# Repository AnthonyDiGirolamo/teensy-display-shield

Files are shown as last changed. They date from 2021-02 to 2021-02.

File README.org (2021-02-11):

* teensy-display-shield

  Handheld [[https://excamera.com/sphinx/gameduino3/][Gameduino3]] display shield for the [[https://www.pjrc.com/store/teensy41.html][Teensy 4.1]], [[https://www.pjrc.com/store/teensy36.html][3.6]] or [[https://www.adafruit.com/category/946][Adafruit Feather form
  factor boards]].

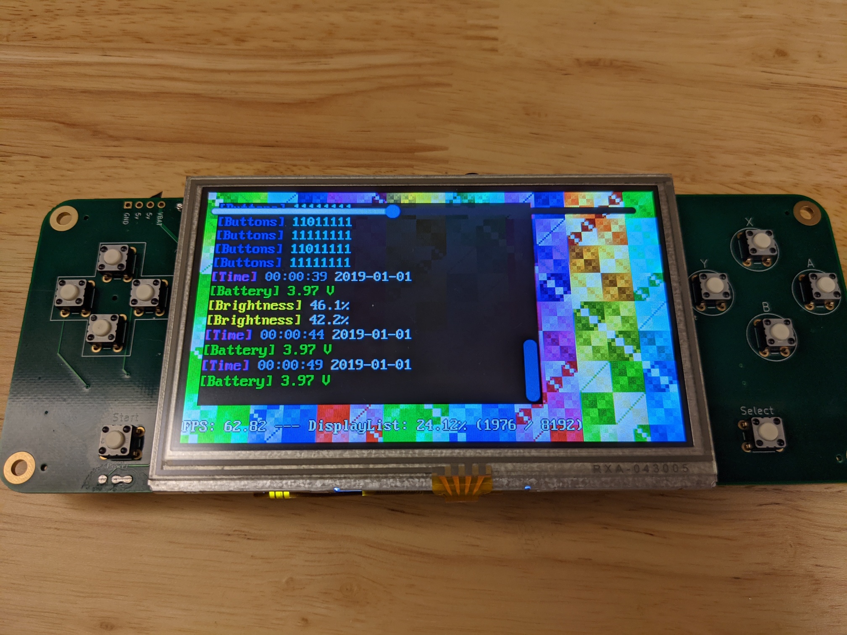
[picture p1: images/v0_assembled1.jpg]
  

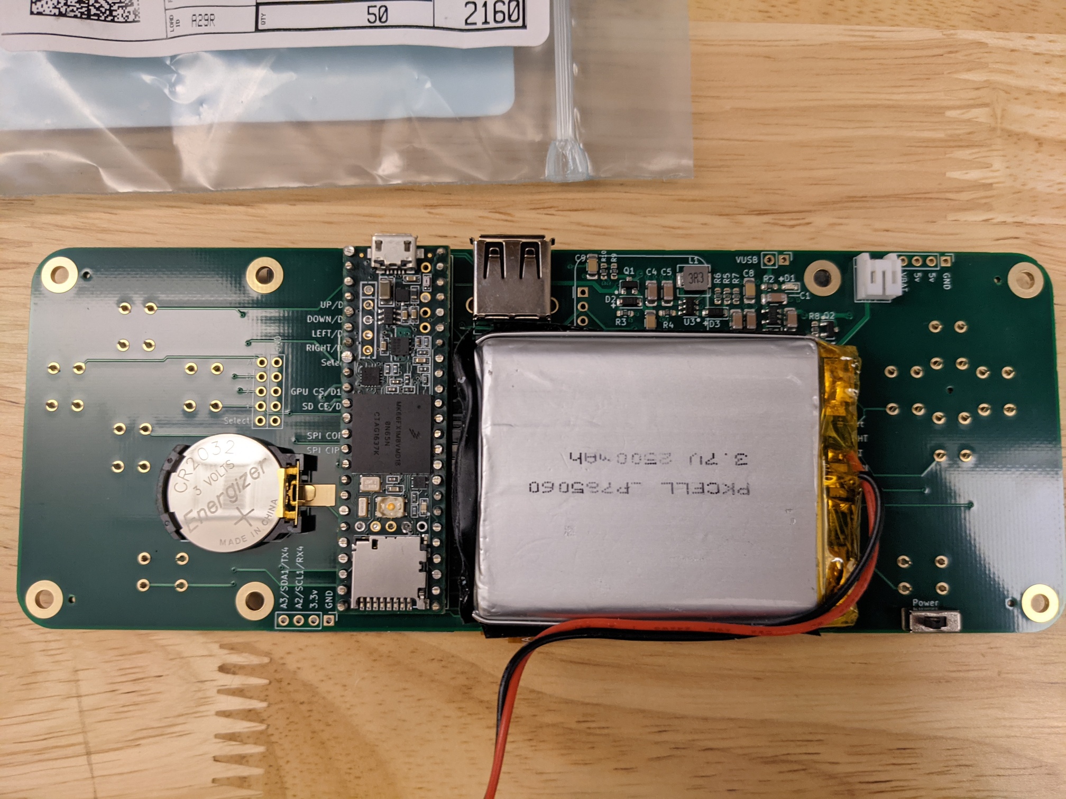
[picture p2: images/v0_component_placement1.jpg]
  

** Version 0

*** Features

    - Teensy and Feather headers.
    - Arduino shield header for use with a Gameduino3 screen.
    - USB-A host jack for Teensy 3.6 and 4.1 boards. For plugging in an external
      keyboard, mouse, or controller.
    - 3v coin cell footprint for Teensy RTC.
    - Through hole buttons for up, down, left, right, a, b, x, y, start, select.
    - On board power:
      - LiPo charging using the [[https://lcsc.com/product-detail/PMIC-Battery-Management_TOPPOWER-Nanjing-Extension-Microelectronics-TP4054_C32574.html][TP4054]] (at 500mA charge-rate).
      - 5 volt boost regulator using the [[https://lcsc.com/product-detail/DC-DC-Converters_Feeling-Tech-FP6291LR-G1_C18701.html][FP6291]]. This powers the Gameduino3 and Teensy.
      - Load sharing between USB and charging.
      - Battery power slide switch.

*** Eratta

    Charging the battery won't work with the power switch in the off
    positon. One cut and jumper wire is needed. See these images:

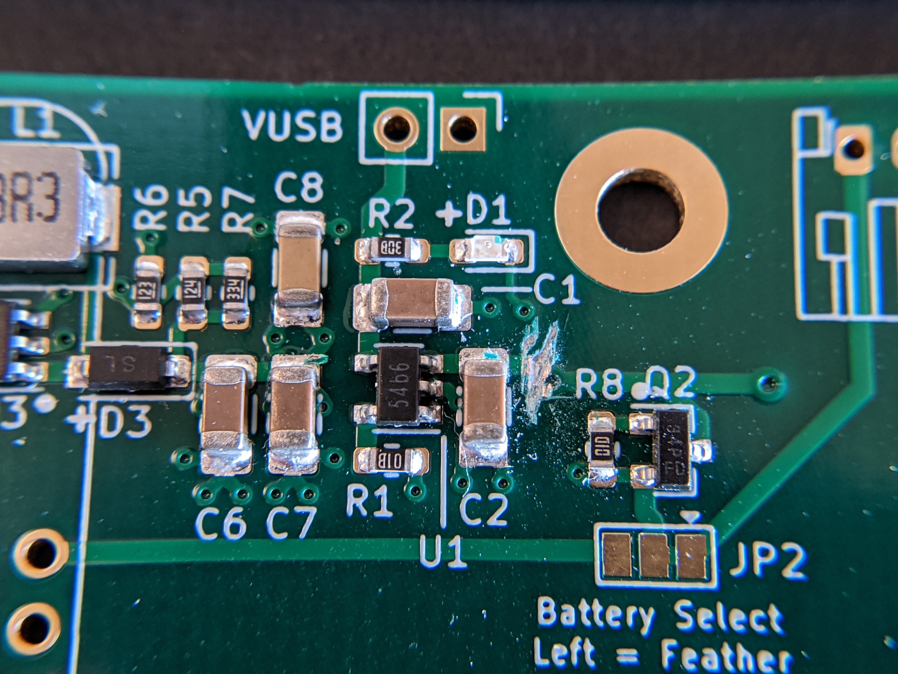
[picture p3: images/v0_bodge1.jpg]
    

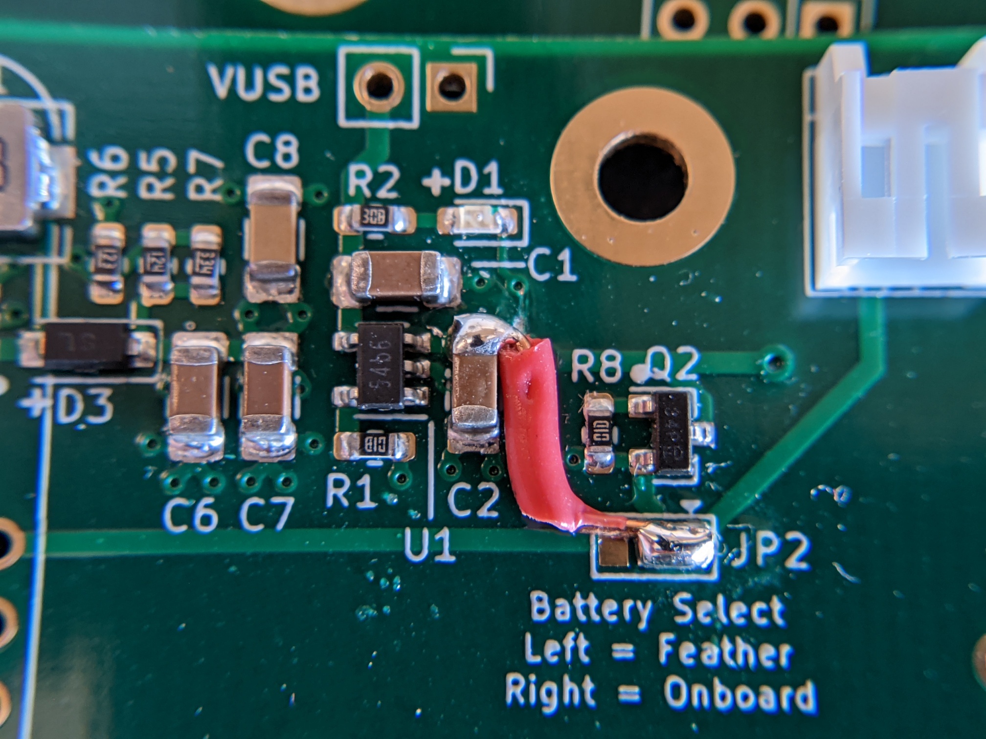
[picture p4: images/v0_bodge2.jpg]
    

** Version 1

*** Required Fixes
    - Correct missing silkscreen pin labels
    - Make all through hole GND connections square pads.

*** Planned Features
    - Push-button on/off operation using [[https://web.archive.org/web/20201001131408/http://www.mosaic-industries.com/embedded-systems/microcontroller-projects/electronic-circuits/push-button-switch-turn-on/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][this schematic]].
    - L and R shoulder buttons.
    - Analog sticks?
    - [[https://www.crowdsupply.com/excamera/gameduino-3x-dazzler][Gameduino 3X Dazzler]] surface mount footprint.
    - Display panel FPC connector and backlight driver.
    - Solder jumpers to control battery charge rate.

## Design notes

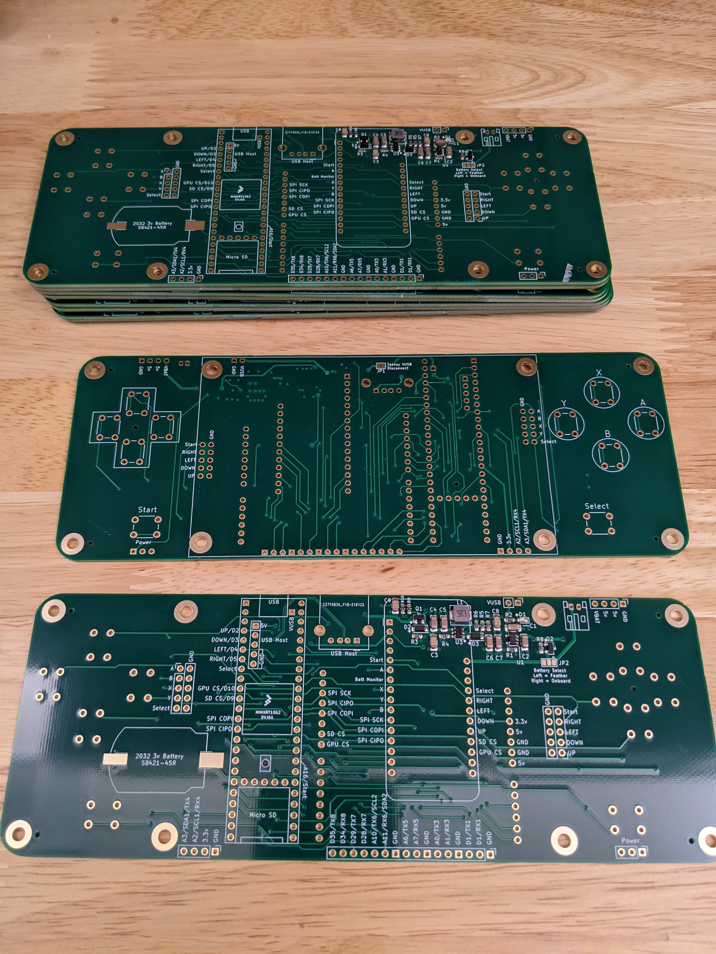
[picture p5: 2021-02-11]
images/v0_boards.jpg

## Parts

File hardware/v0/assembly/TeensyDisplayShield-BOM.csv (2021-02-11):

Comment | Designator | Footprint | LCSC
Adafruit_Feather_Generic | A1 | Module_Latest:Adafruit_Feather
Arduino_UNO_R2 | A2 | Module_Latest:Arduino_UNO_R2
Coin_Cell_2032 | BT1 | Teensy:CoinCell2032HarwinS8421-45R-HandSolder
100nF | C3,C8,C9 | Capacitor_SMD:C_1206_3216Metric_Pad1.33x1.80mm_HandSolder | C24497
10uF | C1,C2,C4,C5,C6,C7 | Capacitor_SMD:C_1206_3216Metric_Pad1.33x1.80mm_HandSolder | C13585
LED-RED | D1 | LED_SMD:LED_0603_1608Metric_Pad1.05x0.95mm_HandSolder | C2286
B5819W | D2,D3 | Diode_SMD:D_SOD-123 | C8598
MountingHole_Pad | H1,H2,H3,H4,H5,H6,H7,H8 | MountingHole:MountingHole_3.2mm_M3_Pad
JSTPH | J1 | Connector_JST:JST_PH_S2B-PH-K_1x02_P2.00mm_Horizontal
USB_A | J2 | Connector_USB:USB_A_Molex_67643_Horizontal
Serial Breakouts | J3 | Connector_PinHeader_2.54mm:PinHeader_1x16_P2.54mm_Vertical
I2C1 Breakout | J4 | Connector_PinHeader_2.54mm:PinHeader_1x04_P2.54mm_Vertical
VBAT/5v Breakout Header | J5 | Connector_PinHeader_2.54mm:PinHeader_1x04_P2.54mm_Vertical
VBUS Breakout Header | J6 | Connector_PinHeader_2.54mm:PinHeader_1x02_P2.54mm_Vertical
Conn_02x05_Top_Bottom | J7,J8 | Connector_PinHeader_2.54mm:PinHeader_2x05_P2.54mm_Vertical
SolderJumper_2_Bridged | JP1 | Jumper:SolderJumper-2_P1.3mm_Bridged2Bar_Pad1.0x1.5mm
Battery Select | JP2 | Jumper:SolderJumper-3_P1.3mm_Bridged12_Pad1.0x1.5mm
3.3uH | L1 | Inductor_SMD:L_Sunlord_MWSA0518_5.4x5.2mm | C408336
DMG3415UQ | Q1,Q2 | Package_TO_SOT_SMD:SOT-23 | C459537
1k | R1 | Resistor_SMD:R_0603_1608Metric_Pad0.98x0.95mm_HandSolder | C21190
10M | R9,R10 | Resistor_SMD:R_0603_1608Metric_Pad0.98x0.95mm_HandSolder | C7250
2k | R2 | Resistor_SMD:R_0603_1608Metric_Pad0.98x0.95mm_HandSolder | C22975
100k | R3,R8 | Resistor_SMD:R_0603_1608Metric_Pad0.98x0.95mm_HandSolder | C25803
10k | R4 | Resistor_SMD:R_0603_1608Metric_Pad0.98x0.95mm_HandSolder | C25804
120k | R5 | Resistor_SMD:R_0603_1608Metric_Pad0.98x0.95mm_HandSolder | C25808
12k | R6 | Resistor_SMD:R_0603_1608Metric_Pad0.98x0.95mm_HandSolder | C22790
330k | R7 | Resistor_SMD:R_0603_1608Metric_Pad0.98x0.95mm_HandSolder | C23137
Battery Switch | SW1 | Connector_PinHeader_2.54mm:PinHeader_1x03_P2.54mm_Vertical
SW_Push | SW2,SW3,SW4,SW5,SW6,SW7,SW8,SW9,SW10,SW11 | Button_Switch_THT:SW_PUSH_6mm
TP4054 | U1 | Package_TO_SOT_SMD:SOT-23-5 | C32574
Teensy4.1 | U2 | Teensy:Teensy41NoEthernet
FP6291LR-G1 | U3 | Package_TO_SOT_SMD:SOT-23-6 | C18701

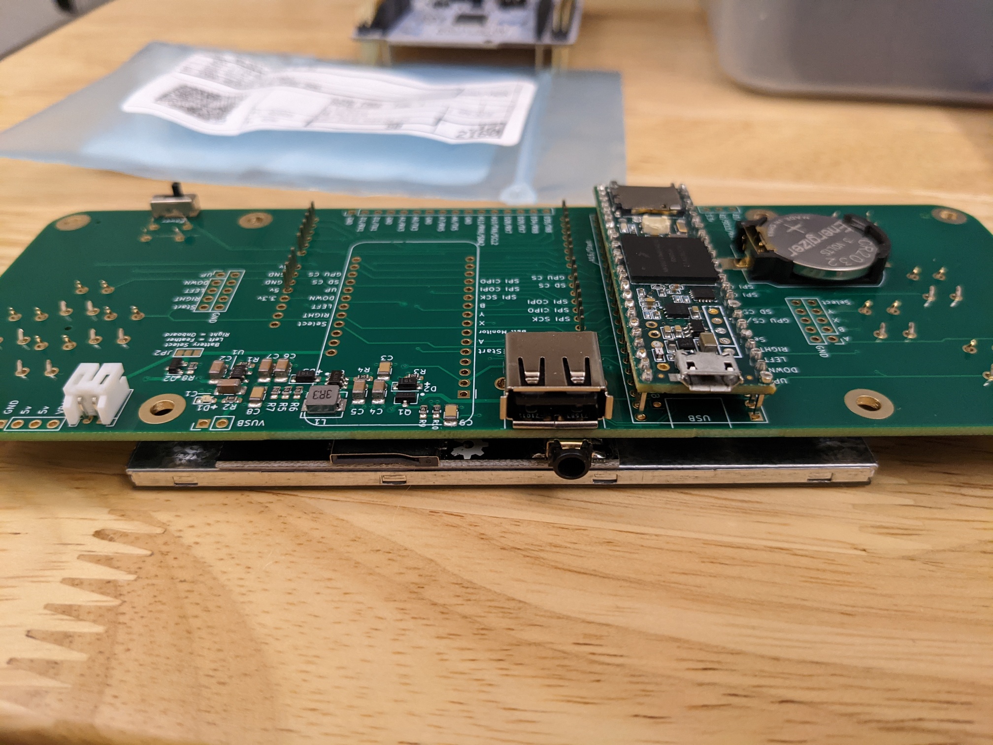
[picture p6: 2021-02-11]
images/v0_component_placement2.jpg

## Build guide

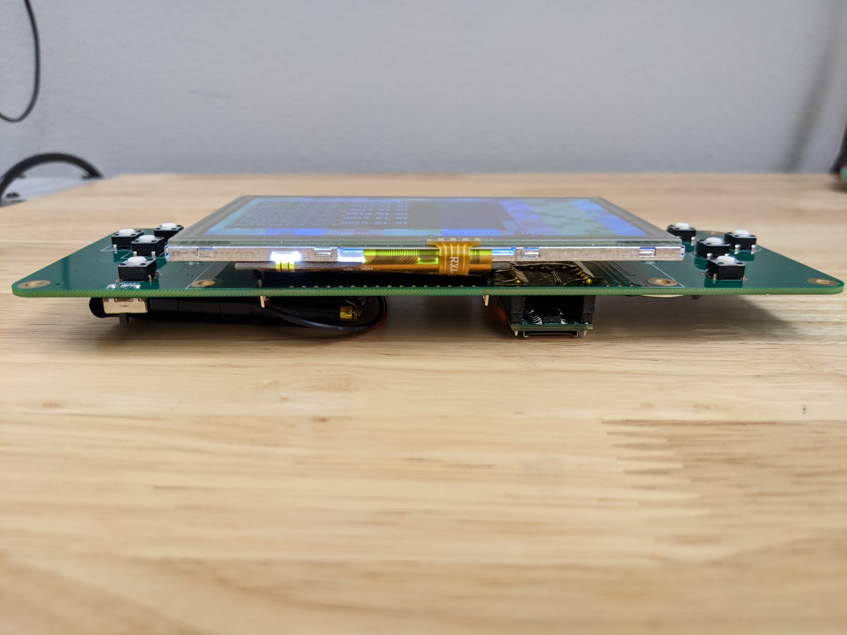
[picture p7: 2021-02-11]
images/v0_assembled2.jpg

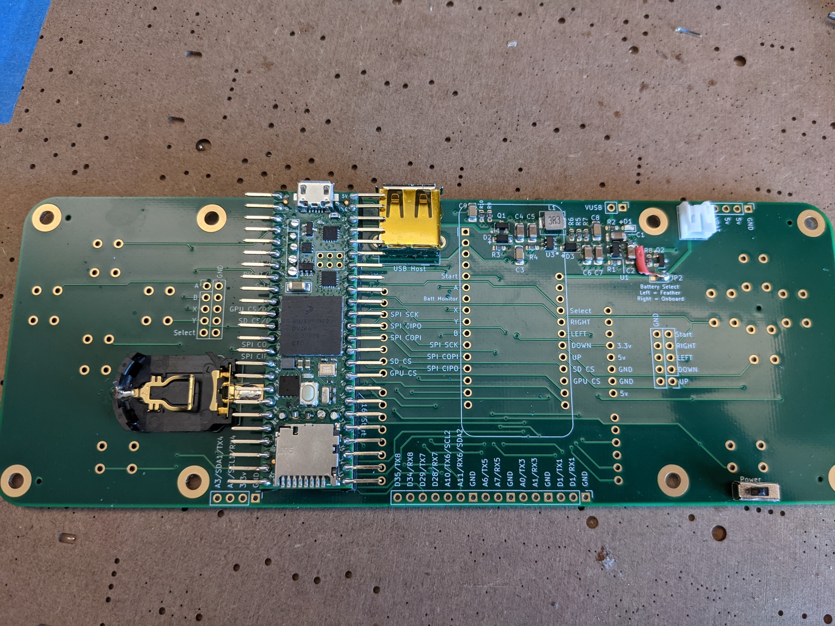
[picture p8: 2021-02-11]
images/v0_assembled3.jpg

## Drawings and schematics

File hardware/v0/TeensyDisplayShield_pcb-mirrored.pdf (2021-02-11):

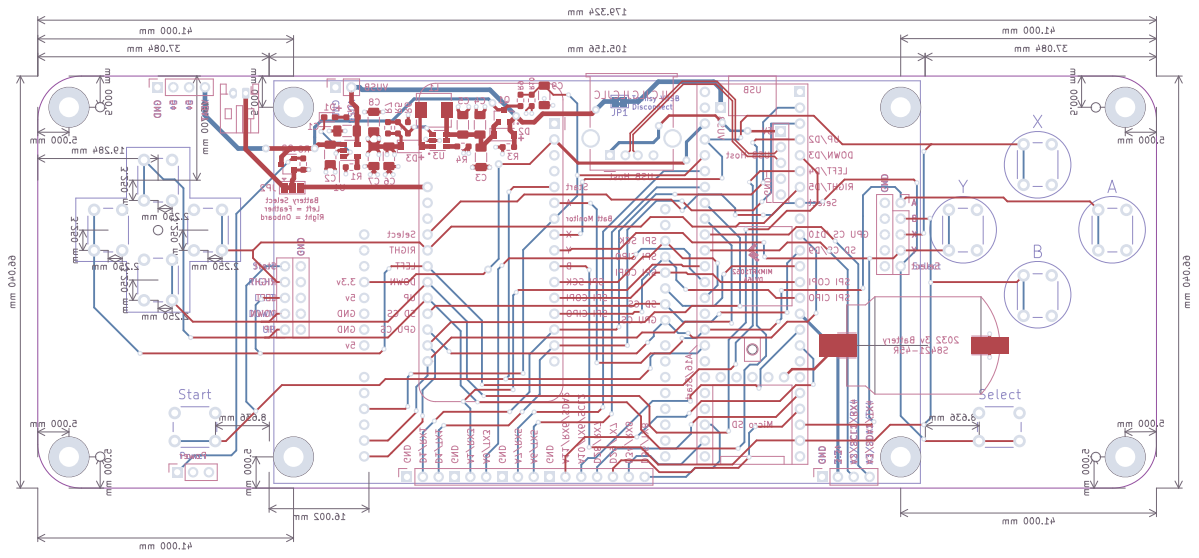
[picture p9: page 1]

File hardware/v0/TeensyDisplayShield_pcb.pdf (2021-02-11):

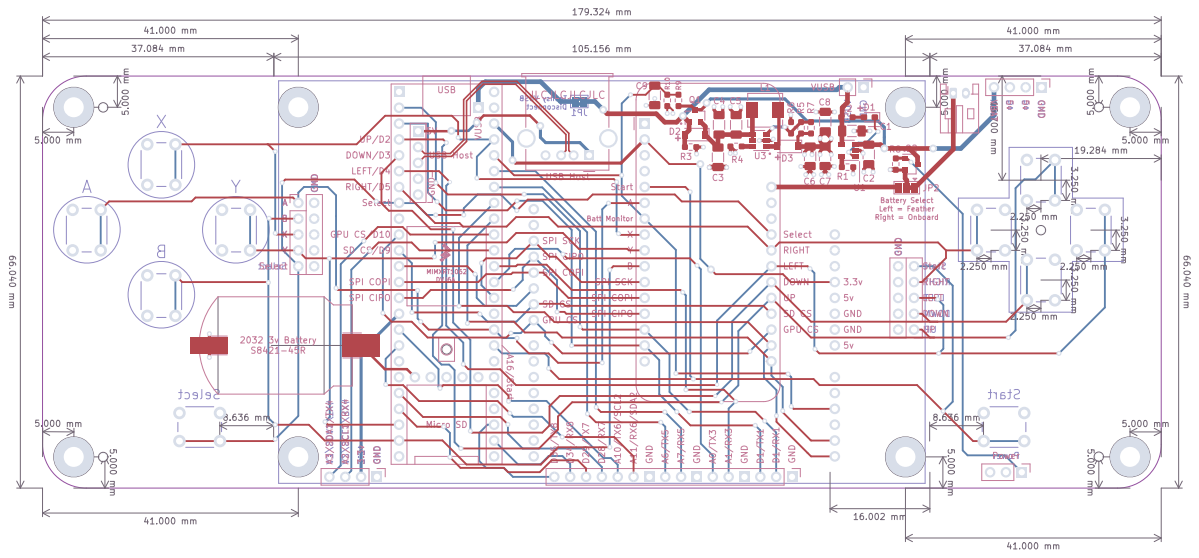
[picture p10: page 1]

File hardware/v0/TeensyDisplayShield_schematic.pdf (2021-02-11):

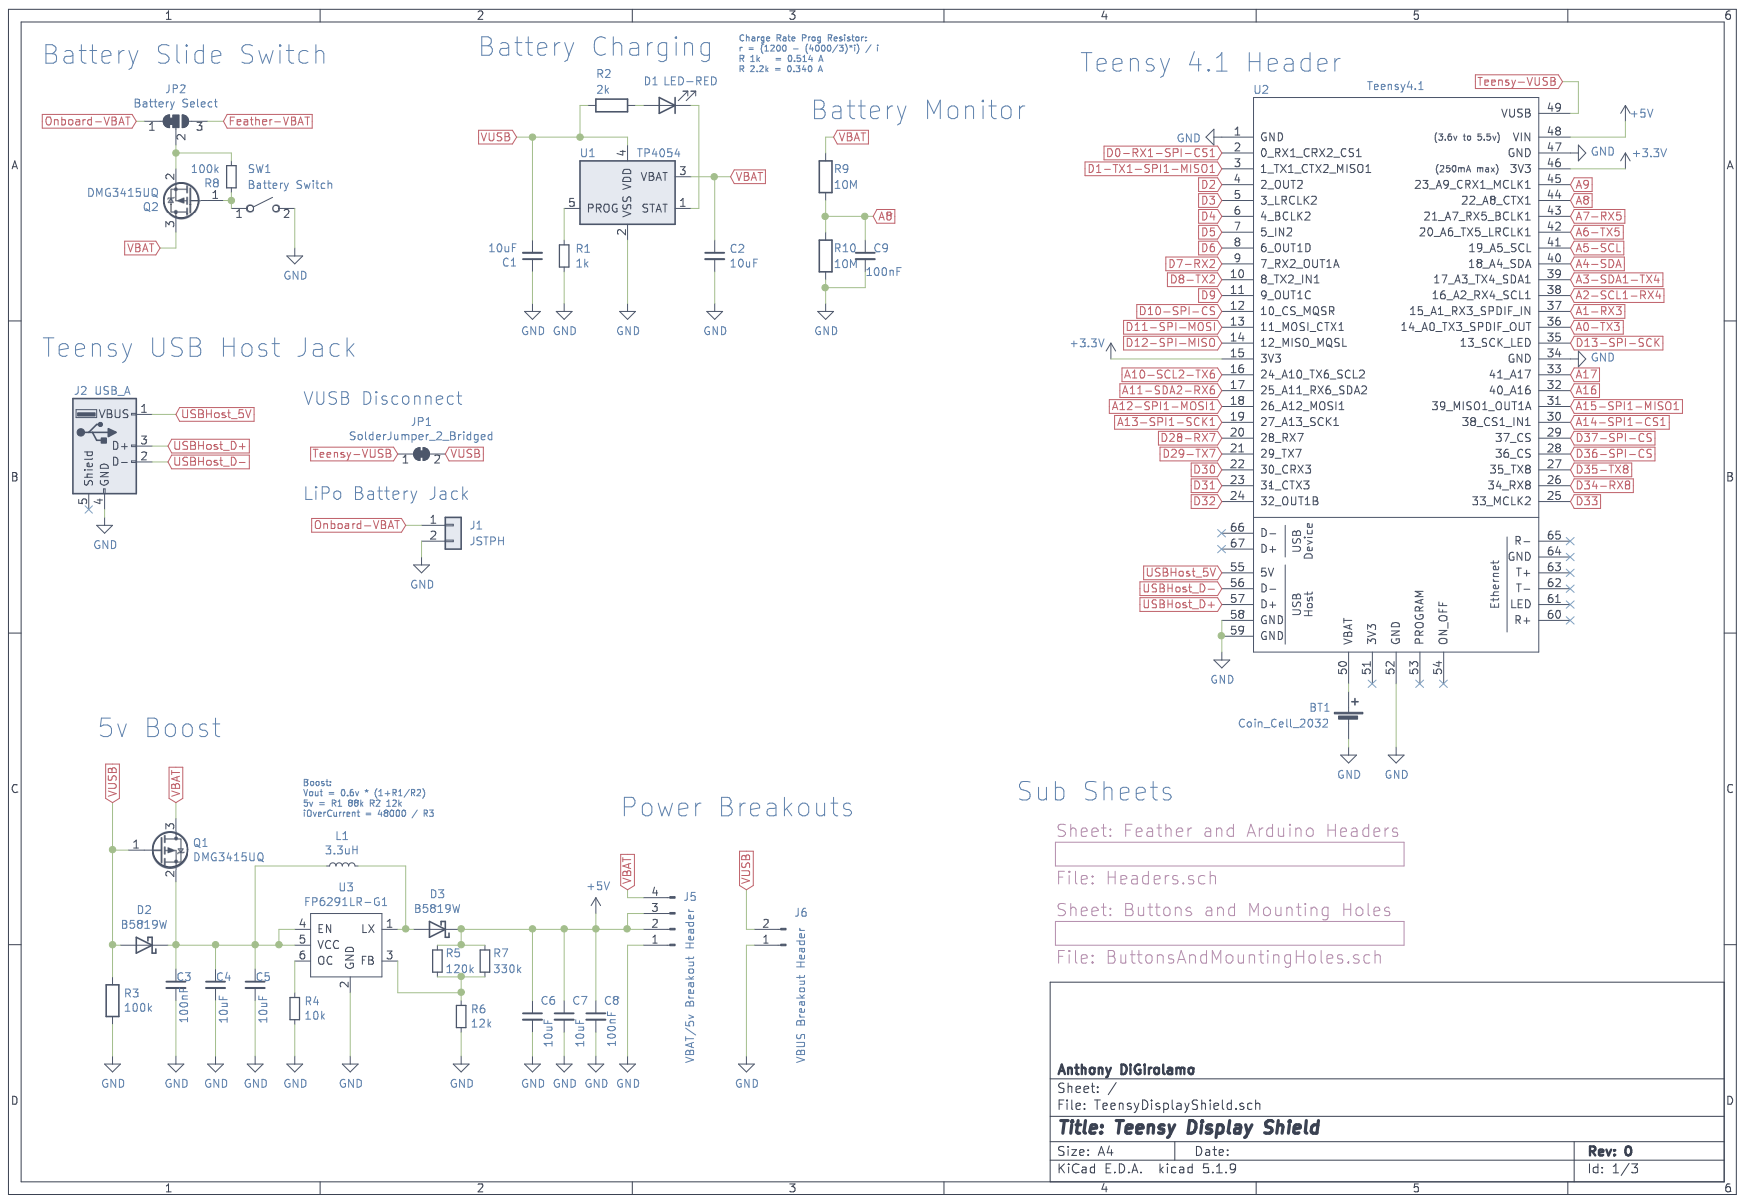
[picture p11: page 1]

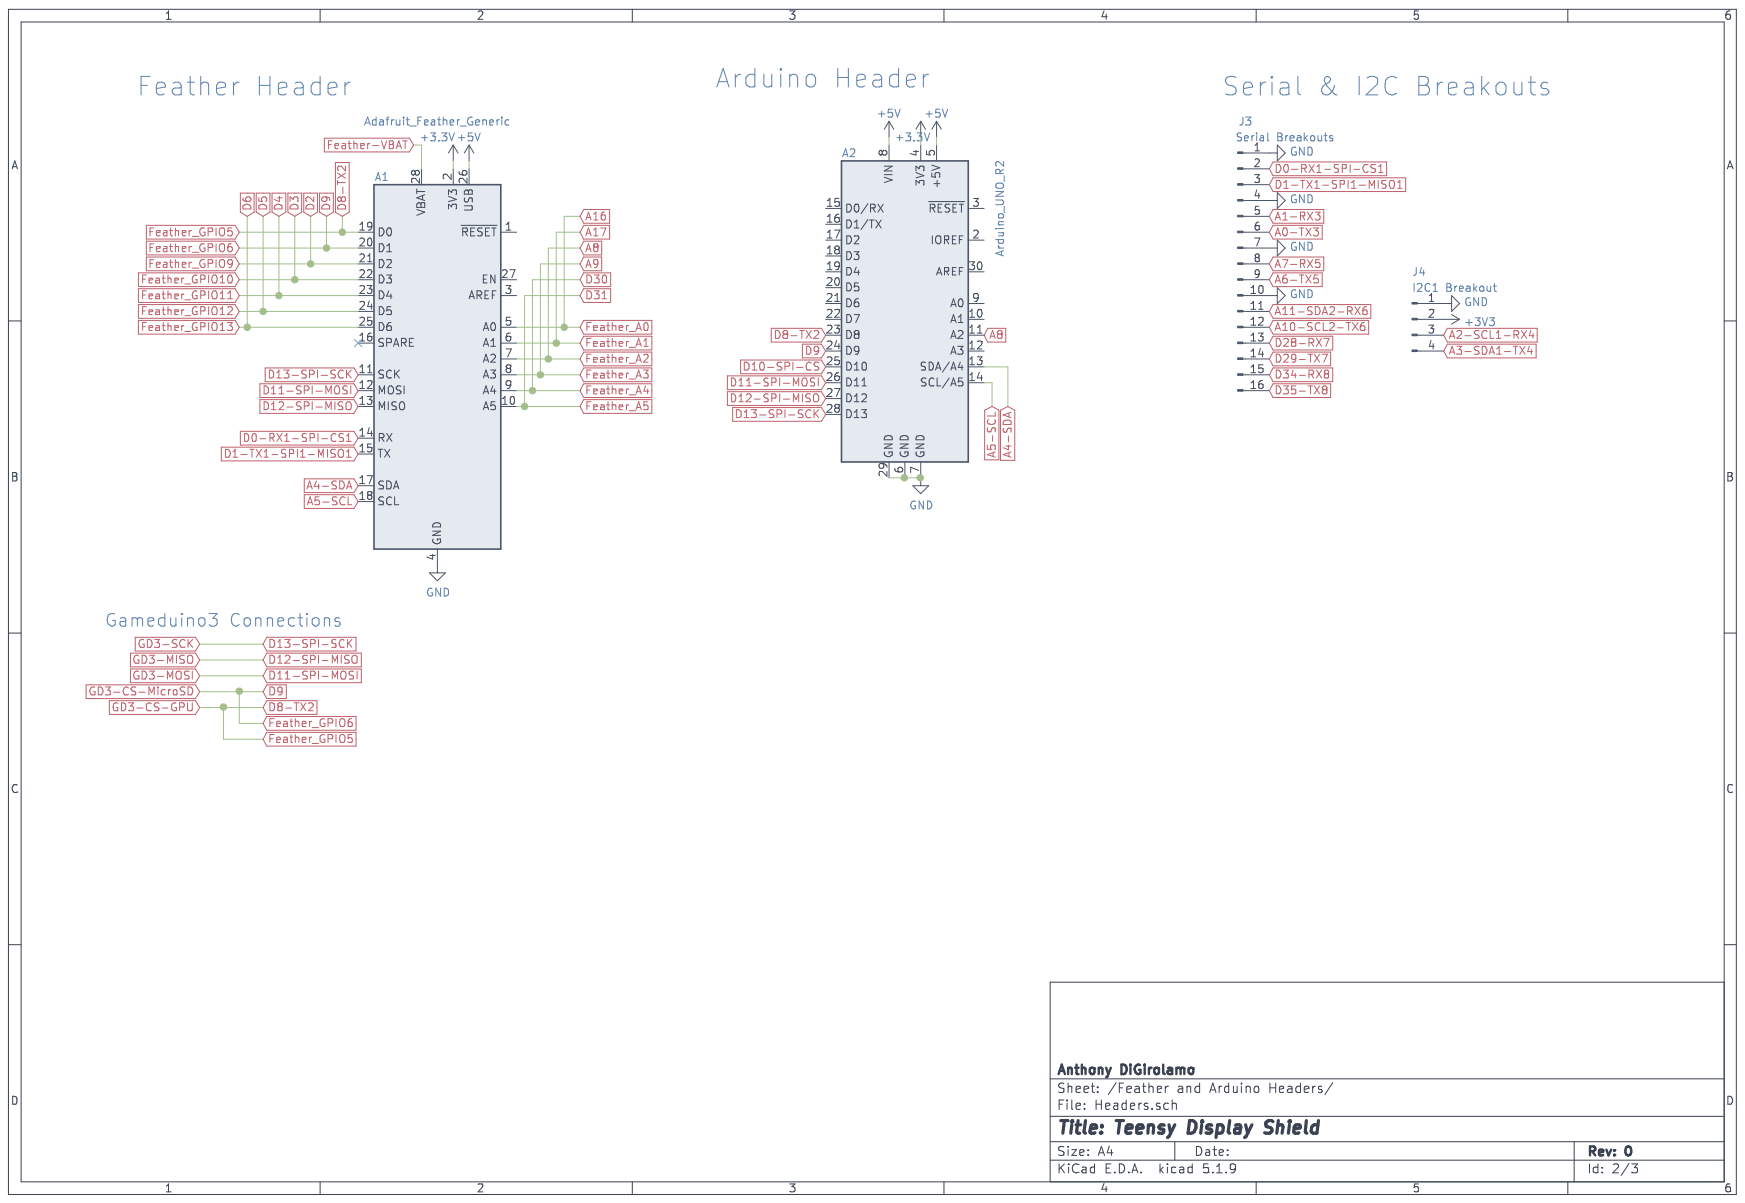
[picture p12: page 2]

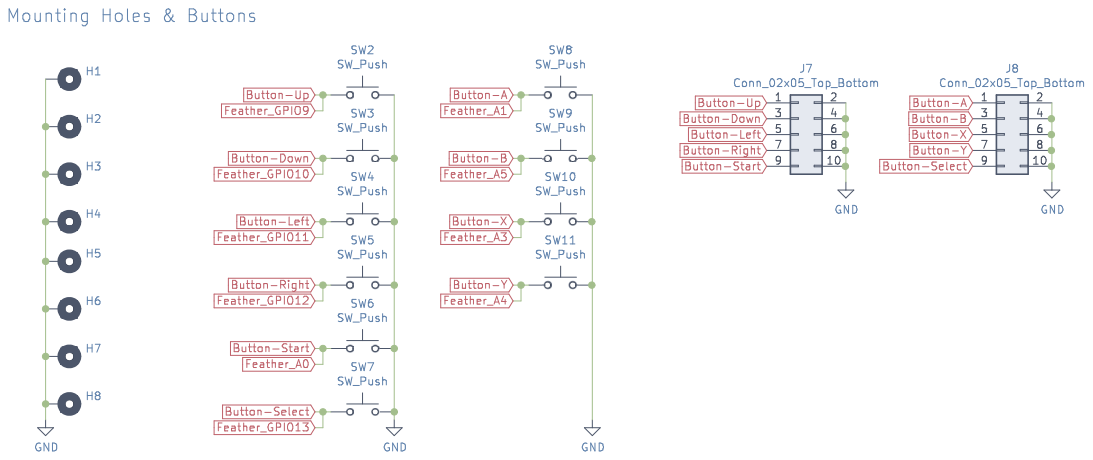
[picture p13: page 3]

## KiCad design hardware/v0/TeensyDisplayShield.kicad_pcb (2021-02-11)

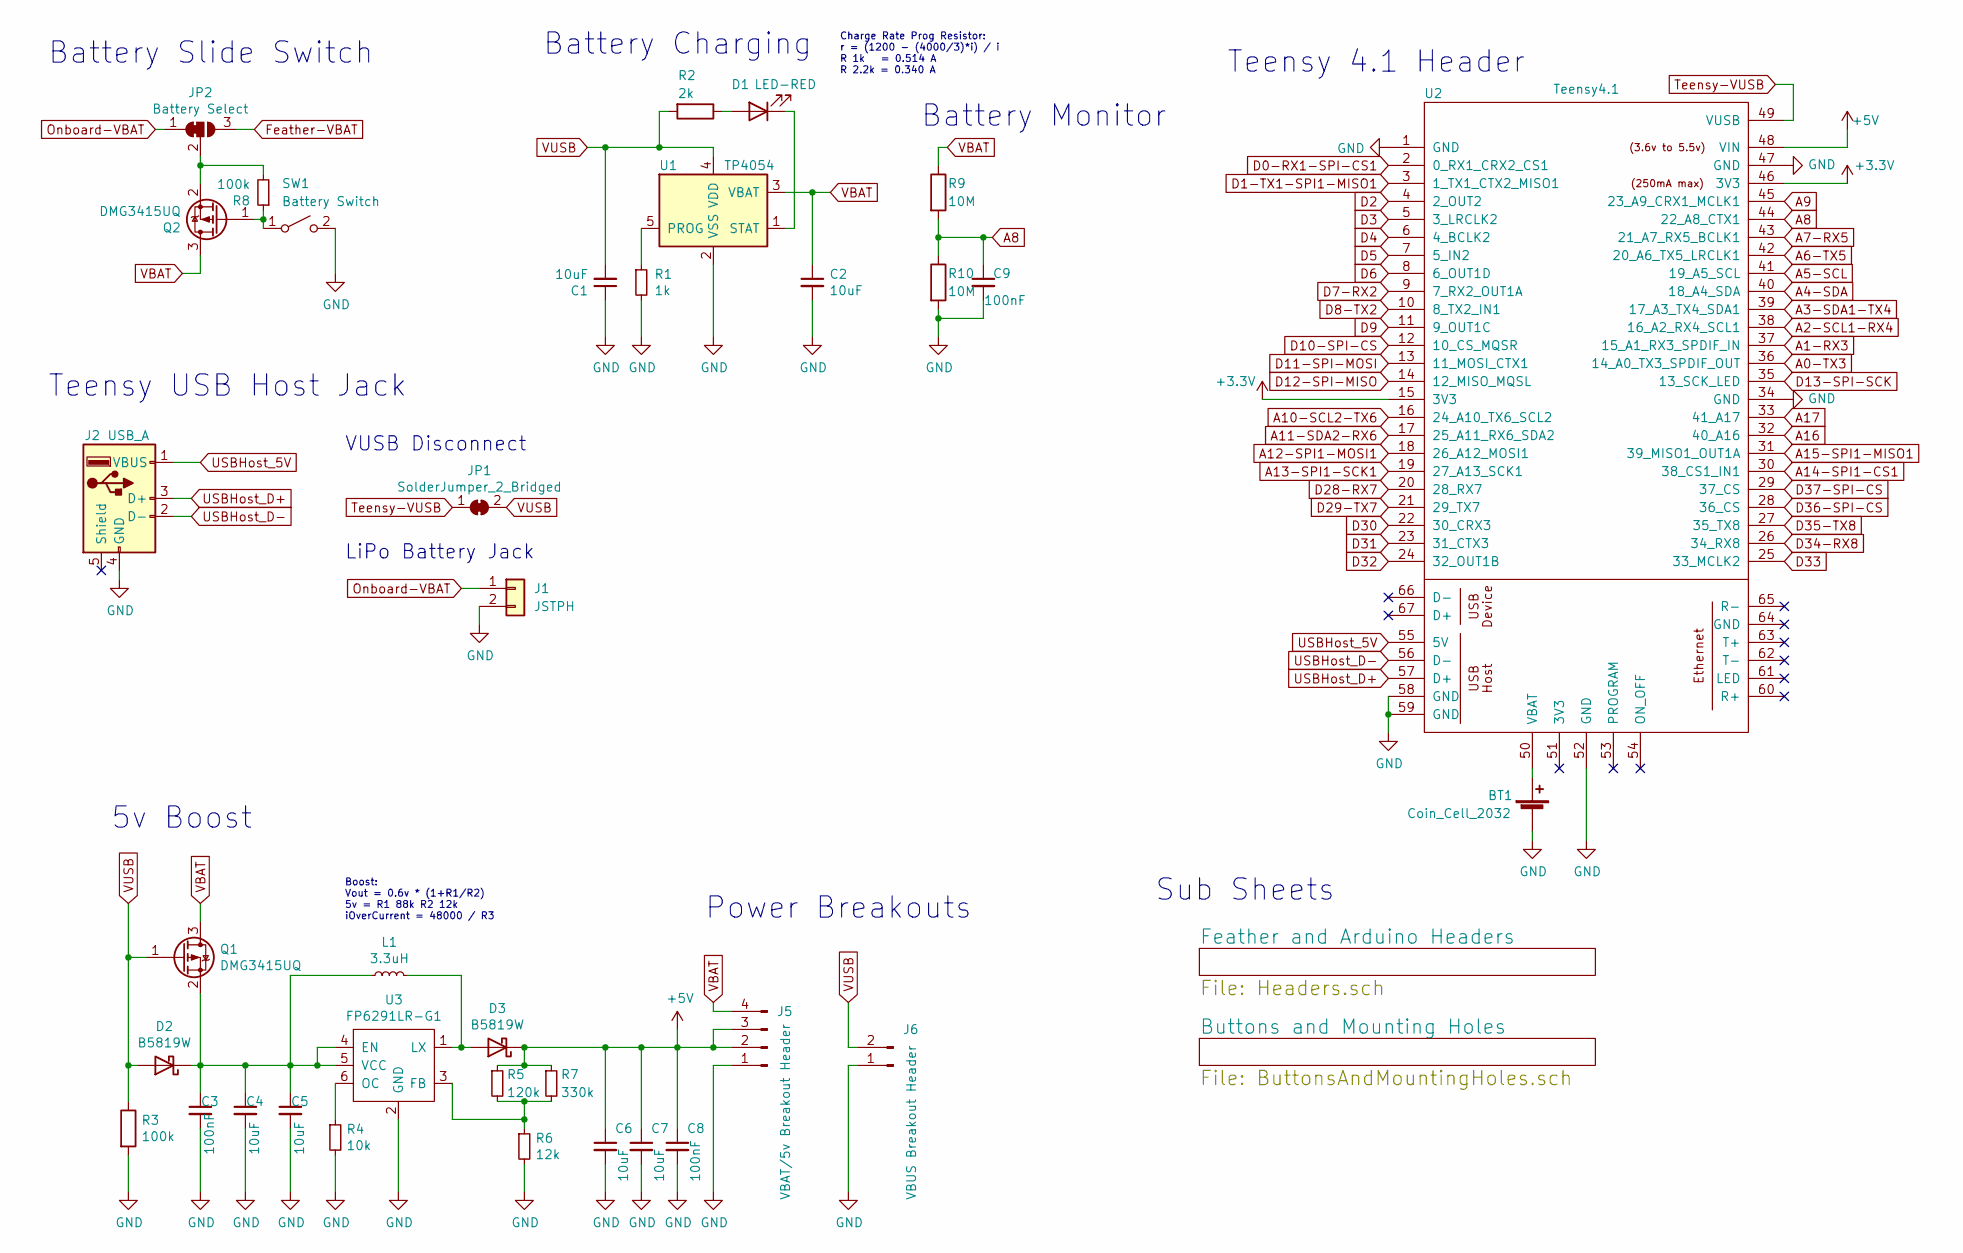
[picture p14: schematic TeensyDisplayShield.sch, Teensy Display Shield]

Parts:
BT1: Coin_Cell_2032; CoinCell2032HarwinS8421-45R-HandSolder
C1, C2, C4, C5, C6, C7: 10uF; C_1206_3216Metric_Pad1.33x1.80mm_HandSolder; LCSC C13585
C3, C8, C9: 100nF; C_1206_3216Metric_Pad1.33x1.80mm_HandSolder; LCSC C24497
D1: LED-RED; LED_0603_1608Metric_Pad1.05x0.95mm_HandSolder; LCSC C2286
D2, D3: B5819W; D_SOD-123; LCSC C8598
J1: JSTPH; JST_PH_S2B-PH-K_1x02_P2.00mm_Horizontal
J2: USB_A; USB_A_Molex_67643_Horizontal
J5: VBAT/5v Breakout Header; PinHeader_1x04_P2.54mm_Vertical
J6: VBUS Breakout Header; PinHeader_1x02_P2.54mm_Vertical
JP1: SolderJumper_2_Bridged; SolderJumper-2_P1.3mm_Bridged2Bar_Pad1.0x1.5mm
JP2: Battery Select; SolderJumper-3_P1.3mm_Bridged12_Pad1.0x1.5mm
L1: 3.3uH; L_Sunlord_MWSA0518_5.4x5.2mm; LCSC C408336
Q1, Q2: DMG3415UQ; SOT-23; LCSC C459537
R1: 1k; R_0603_1608Metric_Pad0.98x0.95mm_HandSolder; LCSC C21190
R2: 2k; R_0603_1608Metric_Pad0.98x0.95mm_HandSolder; LCSC C22975
R3, R8: 100k; R_0603_1608Metric_Pad0.98x0.95mm_HandSolder; LCSC C25803
R4: 10k; R_0603_1608Metric_Pad0.98x0.95mm_HandSolder; LCSC C25804
R5: 120k; R_0603_1608Metric_Pad0.98x0.95mm_HandSolder; LCSC C25808
R6: 12k; R_0603_1608Metric_Pad0.98x0.95mm_HandSolder; LCSC C22790
R7: 330k; R_0603_1608Metric_Pad0.98x0.95mm_HandSolder; LCSC C23137
R9, R10: 10M; R_0603_1608Metric_Pad0.98x0.95mm_HandSolder; LCSC C7250
SW1: Battery Switch; PinHeader_1x03_P2.54mm_Vertical
U1: TP4054; SOT-23-5; LCSC C32574
U2: Teensy4.1; Teensy41NoEthernet
U3: FP6291LR-G1; SOT-23-6; LCSC C18701

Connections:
+5V: C6.1, C7.1, C8.1, D3.1 (K), J5.2, J5.3, R5.1, R7.1, U2.48 (VIN); also elsewhere on the board
A0-TX3: U2.36 (14_A0_TX3_SPDIF_OUT); also elsewhere on the board
A1-RX3: U2.37 (15_A1_RX3_SPDIF_IN); also elsewhere on the board
A2-SCL1-RX4: U2.38 (16_A2_RX4_SCL1); also elsewhere on the board
A3-SDA1-TX4: U2.39 (17_A3_TX4_SDA1); also elsewhere on the board
A4-SDA: U2.40 (18_A4_SDA); also elsewhere on the board
A5-SCL: U2.41 (19_A5_SCL); also elsewhere on the board
A6-TX5: U2.42 (20_A6_TX5_LRCLK1); also elsewhere on the board
A7-RX5: U2.43 (21_A7_RX5_BCLK1); also elsewhere on the board
A8: C9.1, R9.2, R10.1, U2.44 (22_A8_CTX1); also elsewhere on the board
A9: U2.45 (23_A9_CRX1_MCLK1); also elsewhere on the board
A10-SCL2-TX6: U2.16 (24_A10_TX6_SCL2); also elsewhere on the board
A11-SDA2-RX6: U2.17 (25_A11_RX6_SDA2); also elsewhere on the board
A12-SPI1-MOSI1: U2.18 (26_A12_MOSI1)
A13-SPI1-SCK1: U2.19 (27_A13_SCK1)
A14-SPI1-CS1: U2.30 (38_CS1_IN1)
A15-SPI1-MISO1: U2.31 (39_MISO1_OUT1A)
A16: U2.32 (40_A16); also elsewhere on the board
A17: U2.33 (41_A17); also elsewhere on the board
Button-B: U2.23 (31_CTX3); also elsewhere on the board
Button-Down: U2.5 (3_LRCLK2); also elsewhere on the board
Button-Left: U2.6 (4_BCLK2); also elsewhere on the board
Button-Right: U2.7 (5_IN2); also elsewhere on the board
Button-Select: U2.8 (6_OUT1D); also elsewhere on the board
Button-Up: U2.4 (2_OUT2); also elsewhere on the board
Button-Y: U2.22 (30_CRX3); also elsewhere on the board
D0-RX1-SPI-CS1: U2.2 (0_RX1_CRX2_CS1); also elsewhere on the board
D1-TX1-SPI1-MISO1: U2.3 (1_TX1_CTX2_MISO1); also elsewhere on the board
D7-RX2: U2.9 (7_RX2_OUT1A)
D8-TX2: U2.10 (8_TX2_IN1); also elsewhere on the board
D9: U2.11 (9_OUT1C); also elsewhere on the board
D10-SPI-CS: U2.12 (10_CS_MQSR); also elsewhere on the board
D11-SPI-MOSI: U2.13 (11_MOSI_CTX1); also elsewhere on the board
D12-SPI-MISO: U2.14 (12_MISO_MQSL); also elsewhere on the board
D13-SPI-SCK: U2.35 (13_SCK_LED); also elsewhere on the board
D28-RX7: U2.20 (28_RX7); also elsewhere on the board
D29-TX7: U2.21 (29_TX7); also elsewhere on the board
D32: U2.24 (32_OUT1B)
D33: U2.25 (33_MCLK2)
D34-RX8: U2.26 (34_RX8); also elsewhere on the board
D35-TX8: U2.27 (35_TX8); also elsewhere on the board
D36-SPI-CS: U2.28 (36_CS)
D37-SPI-CS: U2.29 (37_CS)
Feather-VBAT: JP2.3 (B); also elsewhere on the board
GND: BT1.2 (-), C1.1, C2.2, C3.2, C4.2, C5.2, C6.2, C7.2, C8.2, C9.2, J1.2, J2.4 (GND), J5.1, J6.1, R1.2, R3.2, R4.2, R6.2, R10.2, SW1.2 (B), U1.2 (VSS), U2.1 (GND), U2.34 (GND), U2.47 (GND), U2.52 (GND), U2.58 (GND), U2.59 (GND), U3.2 (GND); also elsewhere on the board
unnamed: BT1.1 (+), U2.50 (VBAT)
unnamed: C3.1, C4.1, C5.1, D2.1 (K), L1.1, Q1.2 (S), U3.4 (EN), U3.5 (VCC)
unnamed: D1.1 (K), U1.1 (STAT)
unnamed: D1.2 (A), R2.1
unnamed: D3.2 (A), L1.2, U3.1 (LX)
unnamed: JP2.2 (C), Q2.2 (S), R8.2
unnamed: Q2.1 (G), R8.1, SW1.1 (A)
unnamed: R1.1, U1.5 (PROG)
unnamed: R4.1, U3.6 (OC)
unnamed: R5.2, R6.1, R7.2, U3.3 (FB)
Onboard-VBAT: J1.1, JP2.1 (A)
Teensy-VUSB: JP1.1 (A), U2.49 (VUSB)
USBHost_5V: J2.1 (VBUS), U2.55 (5V)
USBHost_D+: J2.3 (D+), U2.57 (D+)
USBHost_D-: J2.2 (D-), U2.56 (D-)
VBAT: C2.1, J5.4, Q1.3 (D), Q2.3 (D), R9.1, U1.3 (VBAT)
VUSB: C1.2, D2.2 (A), J6.2, JP1.2 (B), Q1.1 (G), R2.2, R3.1, U1.4 (VDD)

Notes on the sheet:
Teensy 4.1 Header
5v Boost
Boost: Vout = 0.6v * (1+R1/R2) 5v = R1 88k R2 12k iOverCurrent = 48000 / R3
Battery Slide Switch
Charge Rate Prog Resistor: r = (1200 - (4000/3)*i) / i R 1k = 0.514 A R 2.2k = 0.340 A
Battery Charging
Teensy USB Host Jack
VUSB Disconnect
LiPo Battery Jack
Sub Sheets
Battery Monitor
Power Breakouts

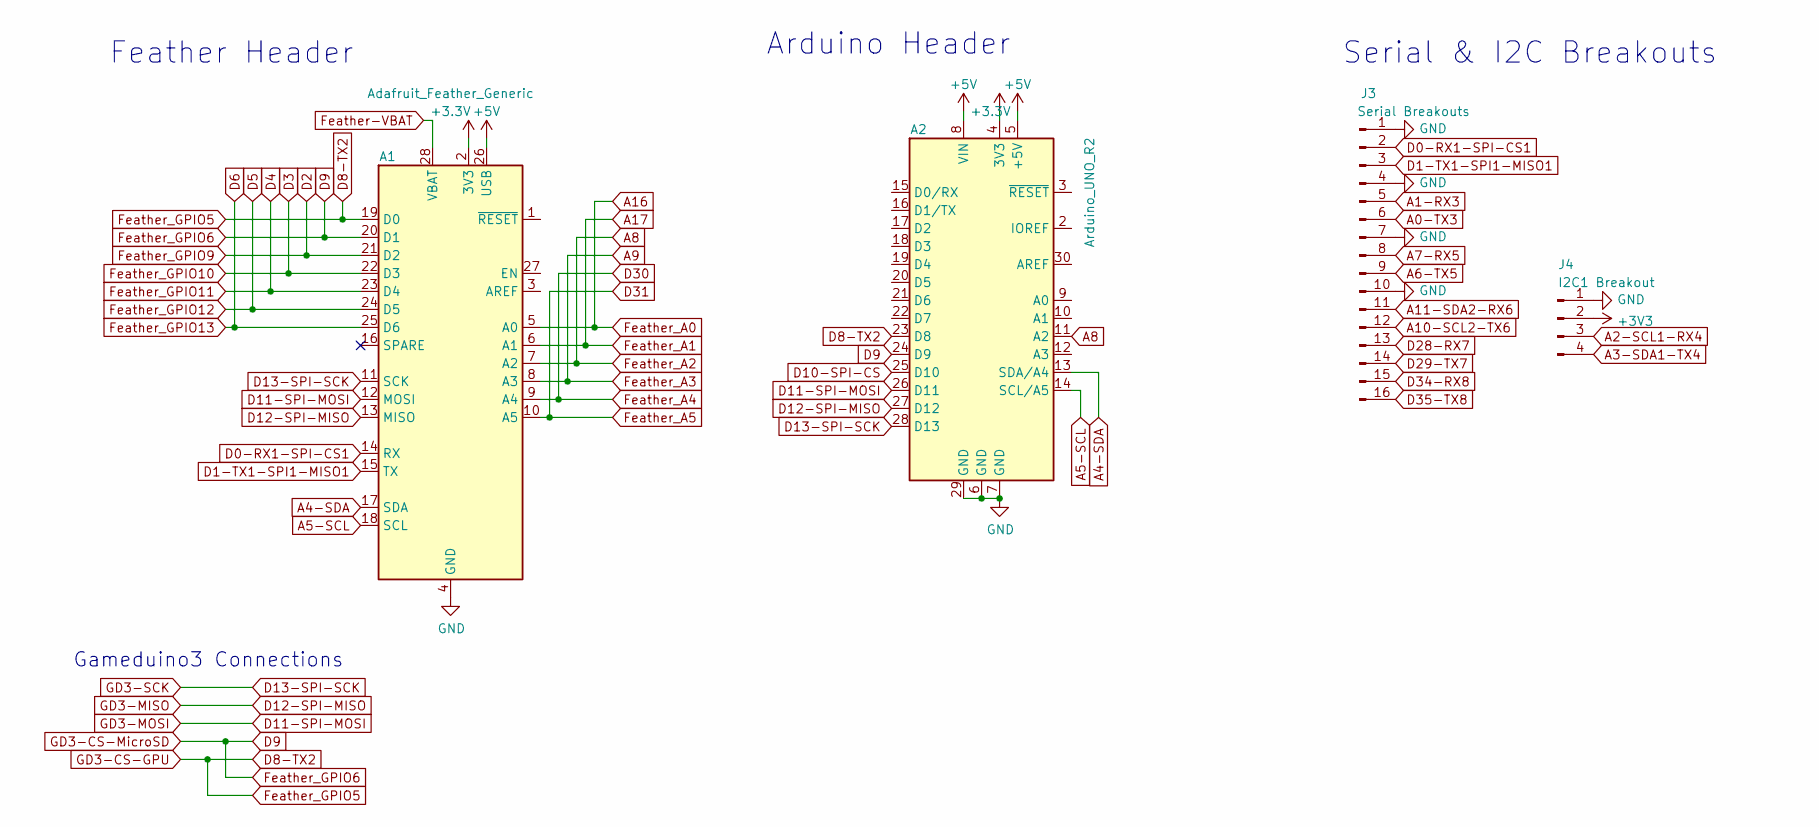
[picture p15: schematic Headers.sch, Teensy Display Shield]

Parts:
A1: Adafruit_Feather_Generic; Adafruit_Feather
A2: Arduino_UNO_R2
J3: Serial Breakouts; PinHeader_1x16_P2.54mm_Vertical
J4: I2C1 Breakout; PinHeader_1x04_P2.54mm_Vertical

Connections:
+5V: A1.26 (USB), A2.5 (+5V), A2.8 (VIN); also elsewhere on the board
A0-TX3: J3.6; also elsewhere on the board
A1-RX3: J3.5; also elsewhere on the board
A2-SCL1-RX4: J4.3; also elsewhere on the board
A3-SDA1-TX4: J4.4; also elsewhere on the board
A4-SDA: A1.17 (SDA), A2.13 (SDA/A4); also elsewhere on the board
A5-SCL: A1.18 (SCL), A2.14 (SCL/A5); also elsewhere on the board
A6-TX5: J3.9; also elsewhere on the board
A7-RX5: J3.8; also elsewhere on the board
A8: A1.7 (A2), A2.11 (A2); also elsewhere on the board
A9: A1.8 (A3); also elsewhere on the board
A10-SCL2-TX6: J3.12; also elsewhere on the board
A11-SDA2-RX6: J3.11; also elsewhere on the board
A16: A1.5 (A0); also elsewhere on the board
A17: A1.6 (A1); also elsewhere on the board
Button-B: A1.10 (A5); also elsewhere on the board
Button-Down: A1.22 (D3); also elsewhere on the board
Button-Left: A1.23 (D4); also elsewhere on the board
Button-Right: A1.24 (D5); also elsewhere on the board
Button-Select: A1.25 (D6); also elsewhere on the board
Button-Up: A1.21 (D2); also elsewhere on the board
Button-Y: A1.9 (A4); also elsewhere on the board
D0-RX1-SPI-CS1: A1.14 (RX), J3.2; also elsewhere on the board
D1-TX1-SPI1-MISO1: A1.15 (TX), J3.3; also elsewhere on the board
D8-TX2: A1.19 (D0), A2.23 (D8); also elsewhere on the board
D9: A1.20 (D1), A2.24 (D9); also elsewhere on the board
D10-SPI-CS: A2.25 (D10); also elsewhere on the board
D11-SPI-MOSI: A1.12 (MOSI), A2.26 (D11); also elsewhere on the board
D12-SPI-MISO: A1.13 (MISO), A2.27 (D12); also elsewhere on the board
D13-SPI-SCK: A1.11 (SCK), A2.28 (D13); also elsewhere on the board
D28-RX7: J3.13; also elsewhere on the board
D29-TX7: J3.14; also elsewhere on the board
D34-RX8: J3.15; also elsewhere on the board
D35-TX8: J3.16; also elsewhere on the board
Feather-VBAT: A1.28 (VBAT); also elsewhere on the board
GND: A1.4 (GND), A2.6 (GND), A2.7 (GND), A2.29 (GND), J3.1, J3.4, J3.7, J3.10, J4.1; also elsewhere on the board

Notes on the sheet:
Feather Header
Arduino Header
Gameduino3 Connections
Serial & I2C Breakouts

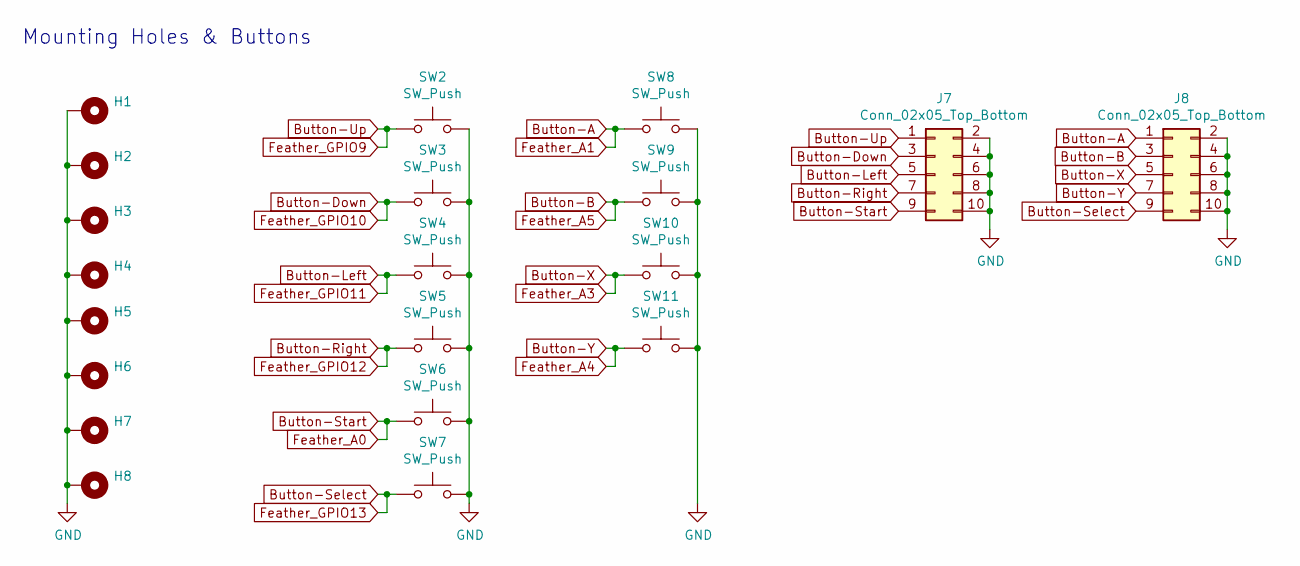
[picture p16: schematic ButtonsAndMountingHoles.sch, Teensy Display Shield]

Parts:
H1, H2, H3, H4, H5, H6, H7, H8: MountingHole_Pad; MountingHole_3.2mm_M3_Pad
J7, J8: Conn_02x05_Top_Bottom; PinHeader_2x05_P2.54mm_Vertical
SW2, SW3, SW4, SW5, SW6, SW7, SW8, SW9, SW10, SW11: SW_Push; SW_PUSH_6mm

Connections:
A9: J8.5, SW10.1; also elsewhere on the board
A16: J7.9, SW6.1; also elsewhere on the board
A17: J8.1, SW8.1; also elsewhere on the board
Button-B: J8.3, SW9.1; also elsewhere on the board
Button-Down: J7.3, SW3.1; also elsewhere on the board
Button-Left: J7.5, SW4.1; also elsewhere on the board
Button-Right: J7.7, SW5.1; also elsewhere on the board
Button-Select: J8.9, SW7.1; also elsewhere on the board
Button-Up: J7.1, SW2.1; also elsewhere on the board
Button-Y: J8.7, SW11.1; also elsewhere on the board
GND: H1.1, H2.1, H3.1, H4.1, H5.1, H6.1, H7.1, H8.1, J7.2, J7.4, J7.6, J7.8, J7.10, J8.2, J8.4, J8.6, J8.8, J8.10, SW2.2, SW3.2, SW4.2, SW5.2, SW6.2, SW7.2, SW8.2, SW9.2, SW10.2, SW11.2; also elsewhere on the board

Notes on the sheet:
Mounting Holes & Buttons

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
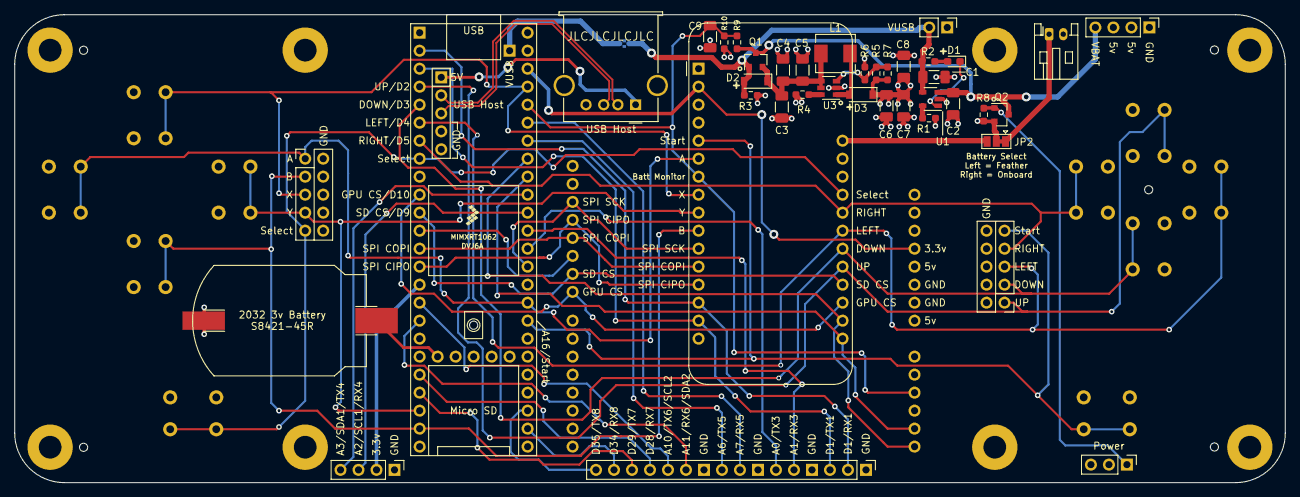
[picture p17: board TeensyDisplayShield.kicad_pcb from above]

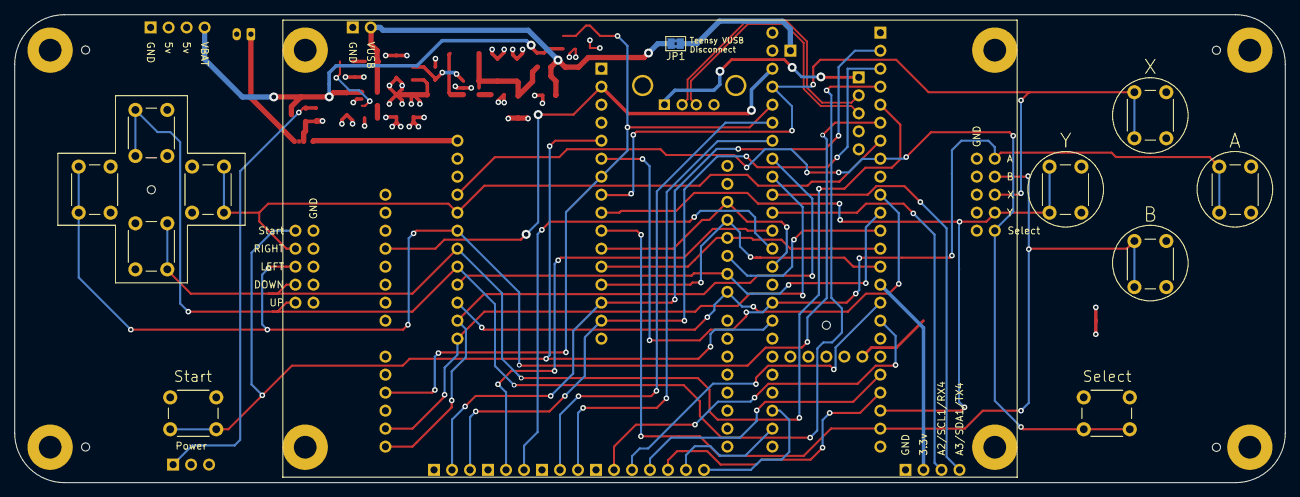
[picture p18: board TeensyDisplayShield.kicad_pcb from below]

Board: 4 copper layers, 179.3 x 66.0 mm, 60 parts (11 on the bottom side), 54 nets.

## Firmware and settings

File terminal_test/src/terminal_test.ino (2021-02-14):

// Allow printing (eg with Serial) using the stream operator
template<class T> inline Print& operator <<(Print &obj,     T arg) { obj.print(arg);    return obj; }
template<>        inline Print& operator <<(Print &obj, float arg) { obj.print(arg, 4); return obj; }

#include <SPI.h>
#include <GD2.h>
#include <GD2Terminal.h>

#include <TimeLib.h>
#include <USBHost_t36.h>

#include <stdlib.h>
#include <stdio.h>

#include "Input.h"
#include "SystemSettings.h"
#include "Munch.h"
#include "Colors.h"


time_t getTeensy3Time() {
  return Teensy3Clock.get();
}


Input controller;
GD2Terminal terminal;
SystemSettings system_settings;
Munch munch;

//=============================================================================
// USB Host Ojbects
//=============================================================================
USBHost myusb;
USBHub hub1(myusb);
USBHub hub2(myusb);
KeyboardController keyboard1(myusb);
KeyboardController keyboard2(myusb);
USBHIDParser hid1(myusb);
USBHIDParser hid2(myusb);
USBHIDParser hid3(myusb);
USBHIDParser hid4(myusb);
USBHIDParser hid5(myusb);
MouseController mouse(myusb);
DigitizerController tablet(myusb);
JoystickController joystick(myusb);
BluetoothController bluet(myusb, true, "0000");   // Version does pairing to device
//BluetoothController bluet(myusb);   // version assumes it already was paired
RawHIDController rawhid2(myusb);

// Lets only include in the lists The most top level type devices we wish to show information for.
//USBDriver *drivers[] = {&keyboard1, &keyboard2, &joystick};
USBDriver *drivers[] = {&keyboard1, &keyboard2, &joystick, &bluet, &hid1, &hid2};

#define CNT_DEVICES (sizeof(drivers)/sizeof(drivers[0]))
//const char * driver_names[CNT_DEVICES] = {"KB1", "KB2", "Joystick(device)"};
const char * driver_names[CNT_DEVICES] = {"KB1", "KB2", "Joystick(device)", "Bluet", "HID1" , "HID2"};
//bool driver_active[CNT_DEVICES] = {false, false, false};
bool driver_active[CNT_DEVICES] = {false, false, false, false, false};

// Lets also look at HID Input devices
USBHIDInput *hiddrivers[] = {&tablet, &joystick, &mouse, &rawhid2};
#define CNT_HIDDEVICES (sizeof(hiddrivers)/sizeof(hiddrivers[0]))
const char * hid_driver_names[CNT_HIDDEVICES] = {"tablet", "joystick", "mouse", "RawHid2"};

bool hid_driver_active[CNT_HIDDEVICES] = {false, false, false, false};

BTHIDInput *bthiddrivers[] = {&joystick, &mouse};
#define CNT_BTHIDDEVICES (sizeof(bthiddrivers)/sizeof(bthiddrivers[0]))
const char * bthid_driver_names[CNT_HIDDEVICES] = {"joystick", "mouse"};
bool bthid_driver_active[CNT_HIDDEVICES] = {false, false};

//=============================================================================
// Other state variables.
//=============================================================================

// Save away values for buttons, x, y, wheel, wheelh
int buttons_cur = 0;
int x_cur = 0,
    y_cur = 0,
    z_cur = 0;
int x2_cur = 0,
    y2_cur = 0,
    z2_cur = 0,
    L1_cur = 0,
    R1_cur = 0;
int wheel_cur = 0;
int wheelH_cur = 0;
int axis_cur[10];

String p = "KB1";
bool BT = 0;

int user_axis[64];
uint32_t buttons_prev = 0;
uint32_t buttons;

bool show_changed_only = false;
bool new_device_detected = false;
int16_t y_position_after_device_info = 0;

uint8_t joystick_left_trigger_value = 0;
uint8_t joystick_right_trigger_value = 0;
uint64_t joystick_full_notify_mask = (uint64_t) - 1;


// Standard GD3 Chip Select Pins
#define GD3_CS 8
#define GD3_SDCS 9

// // Example custom pins
// #define GD3_CS 21
// #define GD3_SDCS 20
// #define GD3_SCLK 14
// #define GD3_MOSI 7
// #define GD3_MISO 12

bool OnReceiveHidData(uint32_t usage, const uint8_t *data, uint32_t len);
void OnPress(int key);
void OnHIDExtrasRelease(uint32_t top, uint16_t key);
void OnHIDExtrasPress(uint32_t top, uint16_t key);

void ProcessJoystickData();
void ProcessMouseData();
void ProcessTabletData();
void UpdateActiveDeviceInfo();

void setup() {
  Serial.begin(115200);
  while (!Serial && millis() < 3000) {}

  // // Teensy custom SPI pins
  // SPI.setMOSI(GD3_MOSI);
  // SPI.setMISO(GD3_MISO);
  // SPI.setSCK(GD3_SCLK);

  SPI.begin();

  // Gameduino3 Setup
  Serial.println("GD.begin()");
  GD.begin(~GD_STORAGE, GD3_CS, GD3_SDCS);
  // GD.begin(GD_CALIBRATE | GD_TRIM | GD_STORAGE, GD3_CS, GD3_SDCS);
  Serial.println("GD.begin() Complete");

  // Enable printf/sprintf to print floats
  // asm(".global _printf_float");

  Serial.println("GD3 Edition");

  setSyncProvider(getTeensy3Time);

  if (timeStatus()!= timeSet) {
    Serial.println("Unable to sync with the RTC");
  } else {
    Serial.println("RTC has set the system time");
  }

  controller.begin();

  // Setup the terminal. Must come after GD.begin -------------------
  terminal.begin(TEXTVGA);
  // terminal.begin(TEXT8X8);
  terminal.set_window_bg_color(0x000000);  // Background window color
  terminal.set_window_opacity(128);  // 0-255

  // Changing Fonts -------------------------------------------------
  // 8X8 Monochrome
  // terminal.set_font_8x8();
  // VGA 16-color
  terminal.set_font_vga();
  // VGA background colors are disabled by default.
  terminal.disable_vga_background_colors();
  // Enable character backgound color. Disables window color&opacity
  // terminal.enable_vga_background_colors();

  // Font changes must be followed by setting a size ---------------
  // Fullscreen
  terminal.set_size_fullscreen();
  // Custom Size
  // terminal.change_size(row_count, column_count);

  // Get FT81X first available ram address (after terminal data) ---
  // terminal.ram_end_address();

  GD.ClearColorRGB(0x000000);
  system_settings.init();
  munch.init(system_settings.ram_end_address());

  Serial.println("USB Host Testing");
  myusb.begin();
  rawhid2.attachReceive(OnReceiveHidData);
  keyboard1.attachPress(OnPress);
  keyboard2.attachPress(OnPress);
  keyboard1.attachExtrasPress(OnHIDExtrasPress);
  keyboard1.attachExtrasRelease(OnHIDExtrasRelease);
  keyboard2.attachExtrasPress(OnHIDExtrasPress);
  keyboard2.attachExtrasRelease(OnHIDExtrasRelease);

}

#define TWO_PI 6.283185307179586476925286766559
float start_offset = 0;

void draw_circles() {
  GD.SaveContext();
  GD.Clear();

  // Draw some moving circles
  GD.PointSize(16 * 30); // means 30 pixels
  GD.Begin(POINTS);
  int start_x = floor(GD.w / 34);
  int start_y = floor(GD.h / 2);
  start_offset += TWO_PI/1024;
  if (start_offset > TWO_PI) {
    start_offset = 0;
  }
  int x;
  for (int i = 0; i < 32; i++) {
    GD.ColorRGB(colors_endesga32[i]);
    x = (i + 2) * start_x;
    GD.Vertex2ii(x, start_y + ((GD.h/3) * sin(x + start_offset)));
  }
  GD.RestoreContext();
}

// Display List size
uint16_t display_list_offset = 0;

// FPS and time per game loop
uint32_t delta_time_start = 0;
uint32_t delta_time_micros = 30000; // initial guess
uint32_t frame_time = 0;
int frame_count = 0;
int last_frame_count = 0;

// Loop Time
// 60 fps = 16667 micros
// 30 fps = 33334 micros
int desired_frame_time = 16667;

void loop() {
  // Frame time start
  delta_time_start = micros();

  // USB Host
  myusb.Task();
  UpdateActiveDeviceInfo(); // Update the display with
  ProcessTabletData(); // Now lets try displaying Tablet data
  ProcessJoystickData(); // And joystick data
  ProcessMouseData(); // Process Mouse Data

  // Update Controller
  controller.update_buttons();

  // Get touchscreen inputs
  GD.get_inputs();

  // Run app update functions. e.g. current_app.update();
  // munch.update();

  system_settings.update_battery_voltage();
  system_settings.update();

  // Draw Screen
  GD.Clear();

  // Draw current app.
  // munch.draw();
  draw_circles();

  // Draw system_settings overlay app.
  system_settings.draw();

  // Draw FPS and Display List Usage for the previous frame.
  float delta_time = (float)delta_time_micros * 1e-6;

  if (millis() > frame_time + 1000) {
    last_frame_count = frame_count;
    frame_count = 0;
    frame_time = millis();
  }

  sprintf(system_settings.line_buffer,
          "Loop: %u -- FPS: %.2f (%d) -- DisplayList: %3.2f%% (%u / 8192, %d instructions) ",
          delta_time_micros,
          1.0 / delta_time,
          (int)last_frame_count,
          100.0 * ((float)display_list_offset/8192),
          display_list_offset,
          (int)floor(display_list_offset/4));
  GD.ColorRGB(COLOR_LIGHT_STEEL_BLUE);
  GD.cmd_text(1, GD.h-16,
              20, 0,
              system_settings.line_buffer);

  // Get the size (current position) of the display list.
  GD.finish();
  display_list_offset = GD.rd16(REG_CMD_DL);

  // Frame time end.
  delta_time_micros = micros() - delta_time_start;

  if (delta_time_micros < desired_frame_time) {
    delay(floor((desired_frame_time - delta_time_micros) * 0.001));
    delta_time_micros = micros() - delta_time_start;
  }

  GD.swap();
  frame_count++;
}

//=============================================================================
// ProcessMouseData
//=============================================================================
bool OnReceiveHidData(uint32_t usage, const uint8_t *data, uint32_t len) {
  // Called for maybe both HIDS for rawhid basic test.  One is for the Teensy
  // to output to Serial. while still having Raw Hid...
  if (usage == 0xFF000080
     ) {
    //Serial.print("RawHIDx data: ");
    //Serial.println(usage, HEX);
    for (uint32_t j = 0; j < len; j++) {
      user_axis[j] = data[j];
    }

    bool something_changed = false;
    if (user_axis[3] != buttons_cur) {
      buttons_cur = user_axis[3];
      something_changed = true;
    }
    if (user_axis[4] != x_cur) {
      x_cur = user_axis[4];
      something_changed = true;
    }
    if (user_axis[5] != y_cur) {
      y_cur = user_axis[5];
      something_changed = true;
    }
    if (tablet.getWheel() != wheel_cur) {
      wheel_cur = 0;
      something_changed = true;
    }
    if (tablet.getWheelH() != wheelH_cur) {
      wheelH_cur = 0;
      something_changed = true;
    }
    if (something_changed) {
      sprintf(system_settings.line_buffer,
              "%d %d %d %d %d\n", buttons_cur, x_cur, y_cur, wheel_cur, wheelH_cur);
      terminal.append_string(system_settings.line_buffer);
    }
  } else {
    // Lets trim off trailing null characters.
    while ((len > 0) && (data[len - 1] == 0)) {
      len--;
    }
    if (len) {
      //Serial.print("RawHid Serial: ");
      //Serial.write(data, len);
    }
  }
  return true;
}

void OnPress(int key)
{
  terminal.append_string("key: ");
  switch (key) {
    case KEYD_UP:        terminal.append_string("UP");    break;
    case KEYD_DOWN:      terminal.append_string("DN");    break;
    case KEYD_LEFT:      terminal.append_string("LEFT");  break;
    case KEYD_RIGHT:     terminal.append_string("RIGHT"); break;
    case KEYD_INSERT:    terminal.append_string("Ins");   break;
    case KEYD_DELETE:    terminal.append_string("Del");   break;
    case KEYD_PAGE_UP:   terminal.append_string("PUP");   break;
    case KEYD_PAGE_DOWN: terminal.append_string("PDN");   break;
    case KEYD_HOME:      terminal.append_string("HOME");  break;
    case KEYD_END:       terminal.append_string("END");   break;
    case KEYD_F1:        terminal.append_string("F1");    break;
    case KEYD_F2:        terminal.append_string("F2");    break;
    case KEYD_F3:        terminal.append_string("F3");    break;
    case KEYD_F4:        terminal.append_string("F4");    break;
    case KEYD_F5:        terminal.append_string("F5");    break;
    case KEYD_F6:        terminal.append_string("F6");    break;
    case KEYD_F7:        terminal.append_string("F7");    break;
    case KEYD_F8:        terminal.append_string("F8");    break;
    case KEYD_F9:        terminal.append_string("F9");    break;
    case KEYD_F10:       terminal.append_string("F10");   break;
    case KEYD_F11:       terminal.append_string("F11");   break;
    case KEYD_F12:       terminal.append_string("F12");   break;
    default: terminal.append_character((char)key); break;
  }
  // tft.print("'  ");
  // tft.print(key);
  // tft.print(" MOD: ");
  // if (keyboard1) {
  //   tft.print(keyboard1.getModifiers(), HEX);
  //   tft.print(" OEM: ");
  //   tft.print(keyboard1.getOemKey(), HEX);
  //   tft.print(" LEDS: ");
  //   tft.println(keyboard1.LEDS(), HEX);
  // } else {
  //   tft.print(keyboard2.getModifiers(), HEX);
  //   tft.print(" OEM: ");
  //   tft.print(keyboard2.getOemKey(), HEX);
  //   tft.print(" LEDS: ");
  //   tft.println(keyboard2.LEDS(), HEX);
  // }
}
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

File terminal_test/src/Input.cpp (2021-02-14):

#include "Input.h"

void Input::begin() {
  pinMode(BUTTON1_PIN_U, INPUT_PULLUP);
  pinMode(BUTTON1_PIN_D, INPUT_PULLUP);
  pinMode(BUTTON1_PIN_L, INPUT_PULLUP);
  pinMode(BUTTON1_PIN_R, INPUT_PULLUP);
  pinMode(BUTTON2_PIN_U, INPUT_PULLUP);
  pinMode(BUTTON2_PIN_D, INPUT_PULLUP);
  pinMode(BUTTON2_PIN_L, INPUT_PULLUP);
  pinMode(BUTTON2_PIN_R, INPUT_PULLUP);
  joystick1_LR_min = 512 - 100;
  joystick1_LR_max = 512 + 100;
  joystick1_UD_min = 512 - 100;
  joystick1_UD_max = 512 + 100;
  joystick2_LR_min = 512 - 100;
  joystick2_LR_max = 512 + 100;
  joystick2_UD_min = 512 - 100;
  joystick2_UD_max = 512 + 100;
  joystick1_deadzone = .4;
  joystick2_deadzone = .4;
  joystick_dpad_diagonal_zone = M_PI * .5 * .3;
}

void Input::update_buttons() {
  buttons_last = buttons;
  buttons = digitalReadFast(BUTTON1_PIN_U) << BUTTON1_U |
    digitalReadFast(BUTTON1_PIN_D) << BUTTON1_D |
    digitalReadFast(BUTTON1_PIN_L) << BUTTON1_L |
    digitalReadFast(BUTTON1_PIN_R) << BUTTON1_R |
    digitalReadFast(BUTTON2_PIN_U) << BUTTON2_U |
    digitalReadFast(BUTTON2_PIN_D) << BUTTON2_D |
    digitalReadFast(BUTTON2_PIN_L) << BUTTON2_L |
    digitalReadFast(BUTTON2_PIN_R) << BUTTON2_R ;

  // Read
  joystick1.set(((float) analogRead(ANALOG1_LR)),
                ((float) analogRead(ANALOG1_UD)));

  // Calibration
  if (joystick1.x < joystick1_LR_min)
    joystick1_LR_min = joystick1.x;
  if (joystick1.x > joystick1_LR_max)
    joystick1_LR_max = joystick1.x;
  if (joystick1.y < joystick1_UD_min)
    joystick1_UD_min = joystick1.y;
  if (joystick1.y > joystick1_UD_max)
    joystick1_UD_max = joystick1.y;
  joystick1.x = map(joystick1.x, joystick1_LR_min, joystick1_LR_max, 0, 1024);
  joystick1.y = map(joystick1.y, joystick1_UD_min, joystick1_UD_max, 0, 1024);

  // Map within the unit circle -1.0 to 1.0
  joystick1 /= 1024;
  joystick1 *= 2;
  joystick1 -= 1.0;
  joystick1.y *= -1.0; // invert the y axis

  // Check for dpad direction
  if (joystick1.length() > joystick1_deadzone) {
    float a = joystick1.angle();
    float angle_diff = (HALF_PI - joystick_dpad_diagonal_zone) * 0.5;

    if ((a < PI && a >= PI-angle_diff)
        || (a <= -PI+angle_diff && a > -PI))
      joystick1_dpad_direction = D_RIGHT;
    // else if ()
    //   joystick1_dpad_direction = D_UP_RIGHT;
    // else if ()
    //   joystick1_dpad_direction = D_UP;
  }
  else
    joystick1_dpad_direction = 0;

  // Read
  joystick2.set(((float) analogRead(ANALOG2_LR)),
                ((float) analogRead(ANALOG2_UD)));

  // Calibration
  if (joystick2.x < joystick2_LR_min)
    joystick2_LR_min = joystick2.x;
  if (joystick2.x > joystick2_LR_max)
    joystick2_LR_max = joystick2.x;
  if (joystick2.y < joystick2_UD_min)
    joystick2_UD_min = joystick2.y;
  if (joystick2.y > joystick2_UD_max)
    joystick2_UD_max = joystick2.y;
  joystick2.x = map(joystick2.x, joystick2_LR_min, joystick2_LR_max, 0, 1024);
  joystick2.y = map(joystick2.y, joystick2_UD_min, joystick2_UD_max, 0, 1024);

  // Map within the unit circle -1.0 to 1.0
  joystick2 /= 1024;
  joystick2 *= 2;
  joystick2 -= 1.0;
  joystick2.x *= -1.0; // invert the x axis

  joystick2_dpad_direction = 0;
}

bool Input::buttons_changed() {
  return buttons != buttons_last;
}

bool Input::button_pressed(uint8_t joystick_button) {
  // BUTTON_SEL is pressed
  // !(this button == 0) and (last button == 1)
  return (!(buttons & (1<<joystick_button))
          && (buttons_last & (1<<joystick_button)));
}

bool Input::button_released(uint8_t joystick_button) {
  // BUTTON_SEL is released
  // !(this button == 1) and (last button == 0)
  return ((buttons & (1<<joystick_button))
          && !(buttons_last & (1<<joystick_button)));
}

bool Input::button_held(uint8_t joystick_button) {
  return !(buttons & (1<<joystick_button));
}

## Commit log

2021-02-11 Add v0 kicad, photos, and terminal test code.
    [ButtonsAndMountingHoles.sch, Headers.sch, MomentaryPowerPushbutton.sch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]
2021-02-14 Update Terminal class API, fix Munch for 800x480 screens
    [SystemSettings.cpp, terminal_test.ino]
